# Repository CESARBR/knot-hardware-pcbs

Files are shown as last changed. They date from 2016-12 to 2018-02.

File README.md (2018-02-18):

# KNoT Hardware PCBs

Here you'll find all the design and outputs files of the hardware that supports KNoT platform application software. Since KNoT is an open-source project, the hardware development also follow the best practices suggested by the open source hardware association (OSHWA).

## Overview

KNoT project includes three board types:

1. Starter Boards
2. Development Boards
3. Reference Design Boards

### Starter Boards
This board offers support for the embedded software development and preliminary hardware evaluation. They're build by the integration of existing modules and are composed of microcontroller, radio and power supply circuit. This boards help popularization of the KNoT Platform because they are cheaper and easier to assembly and distribute to the community.

### Development Board
This PCB is self contained and has two goals: (i) to serve as a development platform with embedded firmware for prototypes that can be validated on field and (ii) to serve as baseline for specific hardware development for final products, as schematics and layouts can be rapidly customized to attend to specific demands.

### Reference Design
The Reference Design is composed of hardware, firmware and (eventually) desktop/mobile software. They are designed to demonstrate the KNoT platform used in real solutions. A Reference Design can be based on a Starter or Development Board tailored to be used in a specific solution.

## Available Boards

The KNoT Platform follows the hub-and-spoke architecture thus comprises of end-nodes, simply called Things, a Gateway to relay the Things messages and cloud applications. Therefore we have two kinds of boards, the Things which are based on [Arduino Pro Mini](https://www.arduino.cc/en/Guide/ArduinoProMini) and the Gateway which is based on a [Raspberry Pi 3](https://www.raspberrypi.org/products/raspberry-pi-3-model-b/).

### KNoT Gateway Starter Board

KNoT Gateway Starter Board consists of a shield board for Raspberry Pi 2 and 3. This shield disposes of:

- 2x8 female header for easily coupling a [nRF24L01+](https://www.nordicsemi.com/eng/Products/2.4GHz-RF/nRF24L01P) module for wireless communication with the KNoT Things
- 3.3V Low Dropout voltage regulator for more stable power feed
- 1x8 female header for coupling the Itead [PN532](https://www.itead.cc/wiki/ITEAD_PN532_NFC_MODULE) NFC card header
- 2x General purpose Push Buttons(with external pull-up resistor circuit and a capacitive high frequency filter)
- 3x General purpose red LEDs
- Prototyping area with 9x16 prototyping holes with 5V, 3V3 and GND connections.

All modules are mapped into the Raspberry Pi pins so no extra jumpers are required to use it, just need to connect the modules. (you can see pins connections in the gateway starter board schematic file).
The connection between the shield modules and the Raspberry Pi pins are made by a male/female 2x20 header thats fit in the Raspberry's GPIO header and ease the access to the Raspberry's GPIO.

### KNoT Gateway Mini Starter Board :new:

KNoT Gateway Mini Starter Board consists of a tiny shield board for Raspberry Pi and saves a lot of space and pins, since it only requires 16 pins from the Raspberry Pi 40-pin header. The board supports the nRF24L01+ radio module and also contains:
- 2x user buttons
  - Things Pairing: starts the pairing process to Things nearby
  - Reset: provides a way to reset the gateway firmware to default parameters
- 3x LEDs
  - Power
  - Connection Status
  - Activity

### KNoT Thing Starter Board

KNoT Thing Starter Board, currently on it third version (`Rev 01.02`) is a device board based on Arduino and nRF24L01+ radio. The board supports the composition of an [Arduino Pro Mini 5V 16MHz](https://www.arduino.cc/en/Main/arduinoBoardProMini), a nRF24L01+ 2.4GHz module and a [FTDI FL232 Module]().
The board also provides the KNoT Status LED and a Reset EEPROM button.

In addition, the board brings an user LED, connected to Arduinos PD5 pin. All the Arduino Pins are available on external headers where user can debug their applications or connect external devices, such as sensors or actuators.

All the board components are plated-through hole technology which makes it easy to manually assembly.

There is also a previous version of this board (`Rev 01.00`) available online on the Upverter E-CAD: [Thing Starter Board](https://upverter.com/CESARKNoT/ea9bba79e71df466/KNoT-nRF24L01/).

### KNoT Thing Development Board

KNoT Thing Development Board consists of an Arduino based PCB with the ATMega328 microcontroler, nRF24L01+ circuit, headers for SPI and I²C communication, push button and status led.

#### Characteristics

 - Supports KNoT version 01.00
 - Compatible with Arduino IDE
 - Supplied via Micro-USB connector
 - nRF24L01+ radio with external antenna
 - ATMega328-AU Micro-controller
 - Programmed through FTDI232RL USB-Serial converter

KNoT Thing DevBoard PCBs are compatible with the Arduino IDE and may be integrated with peripherals through expansion connectors.
Before using the PCB, it's important to burn the bootloader to the Atmega328 micro-controller. For this PCB, the Arduino Pro Mini 3.3V 8MHz bootloader is used ([ATmegaBOOT_168_atmega328_pro_8MHz.hex](https://github.com/arduino/Arduino/blob/master/hardware/arduino/avr/bootloaders/atmega/ATmegaBOOT_168_atmega328_pro_8MHz.hex)). The use of ICSP is recommended for burning the bootloader via the 3x2 header with SPI interface using an Atmel SPI Programmer and Atmel Studio. Besides burning the bootloader, the ATMega328 fuses also need to be programmed via ICSP with the values:
- Extended: 0xFD
- High: 0xDA
- Low: 0xFF

## Development tools

The ECAD tool used is Altium Designer versions 14.2.3 and 14.2.4.

## PCB Files

Each PCB project includes the design files:
 - Components Library
 - Schematics
 - Board Layout

The generated output files are:
 - Bill Of Materials (BOM)
 - Gerber
 - NC Drill
 - PCAD Netlist
 - Assembly Drawing
 - Composite Drawing
 - Pick and Place
 - Schematics (PDF)

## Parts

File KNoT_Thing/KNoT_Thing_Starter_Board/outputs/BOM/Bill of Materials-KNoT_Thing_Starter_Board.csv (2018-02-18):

Comment | Designator | LibRef | Quantity | Supplier 1 | Supplier Part Number 1
CAPC_RADIAL_100 | C1 | CAPC1608L_1 | 1 | Digi-Key | P1175-ND
STATUS | D1 | LED | 1 | Digi-Key | 160-1853-ND
USER | D2 | LED | 1 | Digi-Key | 160-1852-ND
Header 2H | J1, J2, J4, JP1 | Header 2H | 4
Header 6 | J3, J5, J6 | Header 6 | 3
Header 4 | J7 | Header 4 | 1
Arduino Pro Mini 5V 16MHz | MD1 | Arduino Pro Mini 5V 16MHz | 1
nRF24L01+ | MD2 | nRF24L01+ Module | 1
Female header for FTDI module | MD3 | Module_FTDI | 1
Res1 | R1 | Res1 | 1 | Digi-Key | CF18JT10K0CT-ND
Res1 | R2, R3 | Res1 | 2 | Digi-Key | CF18JT150RCT-ND
CLR_EEPROM | S1 | SW-PB | 1 | Digi-Key | 450-1804-ND

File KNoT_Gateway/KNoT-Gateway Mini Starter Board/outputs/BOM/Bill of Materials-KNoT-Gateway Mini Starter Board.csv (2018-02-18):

Comment | Designator | LibRef | Quantity | Supplier 1 | Supplier Part Number 1
Cap 0805 0.1uF | C1 | Cap_0805_0.1uF | 1 | Digi-Key | 445-8883-1-ND
Cap 0805 10uF | C2 | Cap_0805_10uF | 1 | Digi-Key | 709-1229-1-ND
Female 2x8 header | J1 | 2x8 RPi Header | 1 | Digi-Key | S7076-ND
2x4 Female Header | J2 | nRF24L01+ | 1 | Digi-Key | S7107-ND
LED RADIAL 5MM RED | LED1 | LED RADIAL 5MM RED | 1 | Digi-Key | 160-1853-ND
LED RADIAL 5MM GREEN | LED2, LED3 | LED RADIAL 5MM GREEN | 2 | Digi-Key | 160-1852-ND
RES_0805 | R1, R2, R3 | RES_0805 | 3 | Digi-Key | 311-100ARCT-ND
RES_0805 | R4, R5 | RES_0805 | 2 | Digi-Key | 311-4.7KARCT-ND
Push Button - Long | S1 | Push Button L | 1 | Digi-Key | P10880S-ND
Push Button - Short | S2 | Push Button S | 1 | Digi-Key | P10883S-ND

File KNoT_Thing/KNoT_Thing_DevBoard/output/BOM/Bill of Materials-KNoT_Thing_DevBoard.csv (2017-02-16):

Comment | Description | Designator | Footprint | LibRef | Quantity | Supplier 1 | Supplier Part Number 1
Header 7 | Header, 7-Pin | ANALOG IN, DIGITAL | HDR1X7 | Header 7 | 2
Cap_0402 | Chip Capacitor 0402 (1005 metric) | C1, C2, C5, C17, C19 | CAPC1005L | Capacitor_0402 | 5 | Digi-Key | 311-1731-1-ND
Cap_0402 | Chip Capacitor 0402 (1005 metric) | C3, C4 | CAPC1005L | Capacitor_0402 | 2 | Digi-Key | 311-1415-1-ND
Cap_0402 | Chip Capacitor 0402 (1005 metric) | C6, C16 | CAPC1005L | Capacitor_0402 | 2 | Digi-Key | 311-1703-1-ND
Cap_0402 | Chip Capacitor 0402 (1005 metric) | C7 | CAPC1005L | Capacitor_0402 | 1 | Digi-Key | 311-1352-1-ND
Cap_0402 | Chip Capacitor 0402 (1005 metric) | C8 | CAPC1005L | Capacitor_0402 | 1 | Digi-Key | 311-1003-1-ND
Cap_0402 | Chip Capacitor 0402 (1005 metric) | C9, C12 | CAPC1005L | Capacitor_0402 | 2 | Digi-Key | 311-1018-1-ND
Cap_0402 | Chip Capacitor 0402 (1005 metric) | C10 | CAPC1005L | Capacitor_0402 | 1 | Digi-Key | 311-2076-1-ND
Cap_0402 | Chip Capacitor 0402 (1005 metric) | C11 | CAPC1005L | Capacitor_0402 | 1 | Digi-Key | 311-1704-1-ND
Cap_0402 | Chip Capacitor 0402 (1005 metric) | C13 | CAPC1005L | Capacitor_0402 | 1 | Digi-Key | 311-1367-1-ND
Cap_0402 | Chip Capacitor 0402 (1005 metric) | C14 | CAPC1005L | Capacitor_0402 | 1 | Digi-Key | 311-1707-1-ND
Cap0603 | 4.7µF 10V Ceramic Capacitor X5R 0603 | C18, C20 | CAPC1608L | Cap0603 | 2 | Digi-Key | 311-1453-1-ND
0402L050SLKR | PTC Resettable Fuse 6V 500mA Ih Surface Mount 0402 (1005 Metric), Concave | F1 | 0805L | Fuse 2 | 1 | Digi-Key | F2772CT-ND
Header 6 | Header, 6-Pin | I2C | HDR1X6 | Header 6 | 1
32K249-400L5 | SMA Right Angle Jack, Up to 18 GHz, -65 to 165 degC | J2 | ROS-32K249-400L5_V | 32K249-400L5 | 1 | Digi-Key | ARFX1232-ND
Header 3X2 | Header, 3-Pin, Dual row | J5 | HDR2X3 | Header 3X2 | 1
Inductor0402 | Inductor 27nH | L1 | CAPC1005L | Inductor0402 | 1 | Digi-Key | A103711CT-ND
Inductor0402 | Inductor 27nH | L2 | CAPC1005L | Inductor0402 | 1 | Digi-Key | A102559CT-ND
Inductor0402 | Inductor 27nH | L3 | CAPC1005L | Inductor0402 | 1 | Digi-Key | A103706CT-ND
Ferrite | BLM18AG121SN1 FERRITE 120 OHM 500MA 0603 | L4 | 0603-cap | Ferrite | 1 | Digi-Key | 445-2166-1-ND
LED 0603 | LED SMD 0603 | LED1 | 0603_LED | LED 0603 | 1 | Digi-Key | 754-1790-1-ND
LED 0603 | LED SMD 0603 | LED2 | 0603_LED | LED 0603 | 1 | Digi-Key | 754-1789-1-ND
Header 2H | Header, 2-Pin, Right Angle | POWER | HDR1X2 | Header 2H | 1
RES_0402 | Precision Thick Film Chip Resistor, 10 Ohm to 1M Ohm Range, 1% and 0.5% Tolerance, 0805 Size, 1/8 W | R1, R7 | CAPC1005L | RES_0402 | 2 | Digi-Key | 311-2131-1-ND
RES_0402 | Precision Thick Film Chip Resistor, 10 Ohm to 1M Ohm Range, 1% and 0.5% Tolerance, 0805 Size, 1/8 W | R2 | CAPC1005L | RES_0402 | 1 | Digi-Key | 311-22KJRCT-ND
RES_0402 | Precision Thick Film Chip Resistor, 10 Ohm to 1M Ohm Range, 1% and 0.5% Tolerance, 0805 Size, 1/8 W | R3 | CAPC1005L | RES_0402 | 1 | Digi-Key | 311-1.0MJRCT-ND
RES_0402 | Precision Thick Film Chip Resistor, 10 Ohm to 1M Ohm Range, 1% and 0.5% Tolerance, 0805 Size, 1/8 W | R4, R5 | CAPC1005L | RES_0402 | 2 | Digi-Key | 311-330JRCT-ND
RES_0402 | Precision Thick Film Chip Resistor, 10 Ohm to 1M Ohm Range, 1% and 0.5% Tolerance, 0805 Size, 1/8 W | R6 | CAPC1005L | RES_0402 | 1 | Digi-Key | 311-0.0JRTR-ND
SW-SPST | Single-Pole, Single-Throw Switch | S1, S2 | SWITCH TS-1181 | SW-SPST | 2 | Digi-Key | CKN10384CT-ND
ATmega328-AU | 8-bit AVR Microcontroller, 32KB Flash, 1KB EEPROM, 2KB SRAM, 32-pin TQFP, Industrial Grade (-40°C to 85°C) | U1 | 32A_L | ATmega328-AU | 1 | Digi-Key | ATMEGA328-AU-ND
nRF24L01+ QFN20 | IC RF TxRx Only General ISM > 1GHZ 2.4GHz | U2 | QFN20 | nRF24L01+ | 1 | Digi-Key | 1490-1019-ND
FT232RL-Reel | USB UART Asynchronous Serial Data Transfer Chip, 28-pin SSOP, Tape and Reel | U3 | SSOP-28_N | FT232RL-Reel | 1 | Digi-Key | 768-1007-6-ND
MIC5205-3.3YM5 | Voltage Regulator | U4 | SOT23-5 | MIC5205-3.3YM5 | 1 | Digi-Key | 576-1259-1-ND
ZX62-B-5PA-33 | USB Connector | USB | Micro USB b | ZX62-B-5PA-33 | 1 | Digi-Key | H125270CT-ND
8 MHz | Crystal FOXSLF/080-20 | Y1 | CX5032GB | XTAL | 1 | Digi-Key | 1253-1373-1-ND
16 MHz | Crystal FOXSLF/080-20 | Y2 | SPK-16M-5032 | XTAL_SMD | 1 | Digi-Key | 887-1708-1-ND

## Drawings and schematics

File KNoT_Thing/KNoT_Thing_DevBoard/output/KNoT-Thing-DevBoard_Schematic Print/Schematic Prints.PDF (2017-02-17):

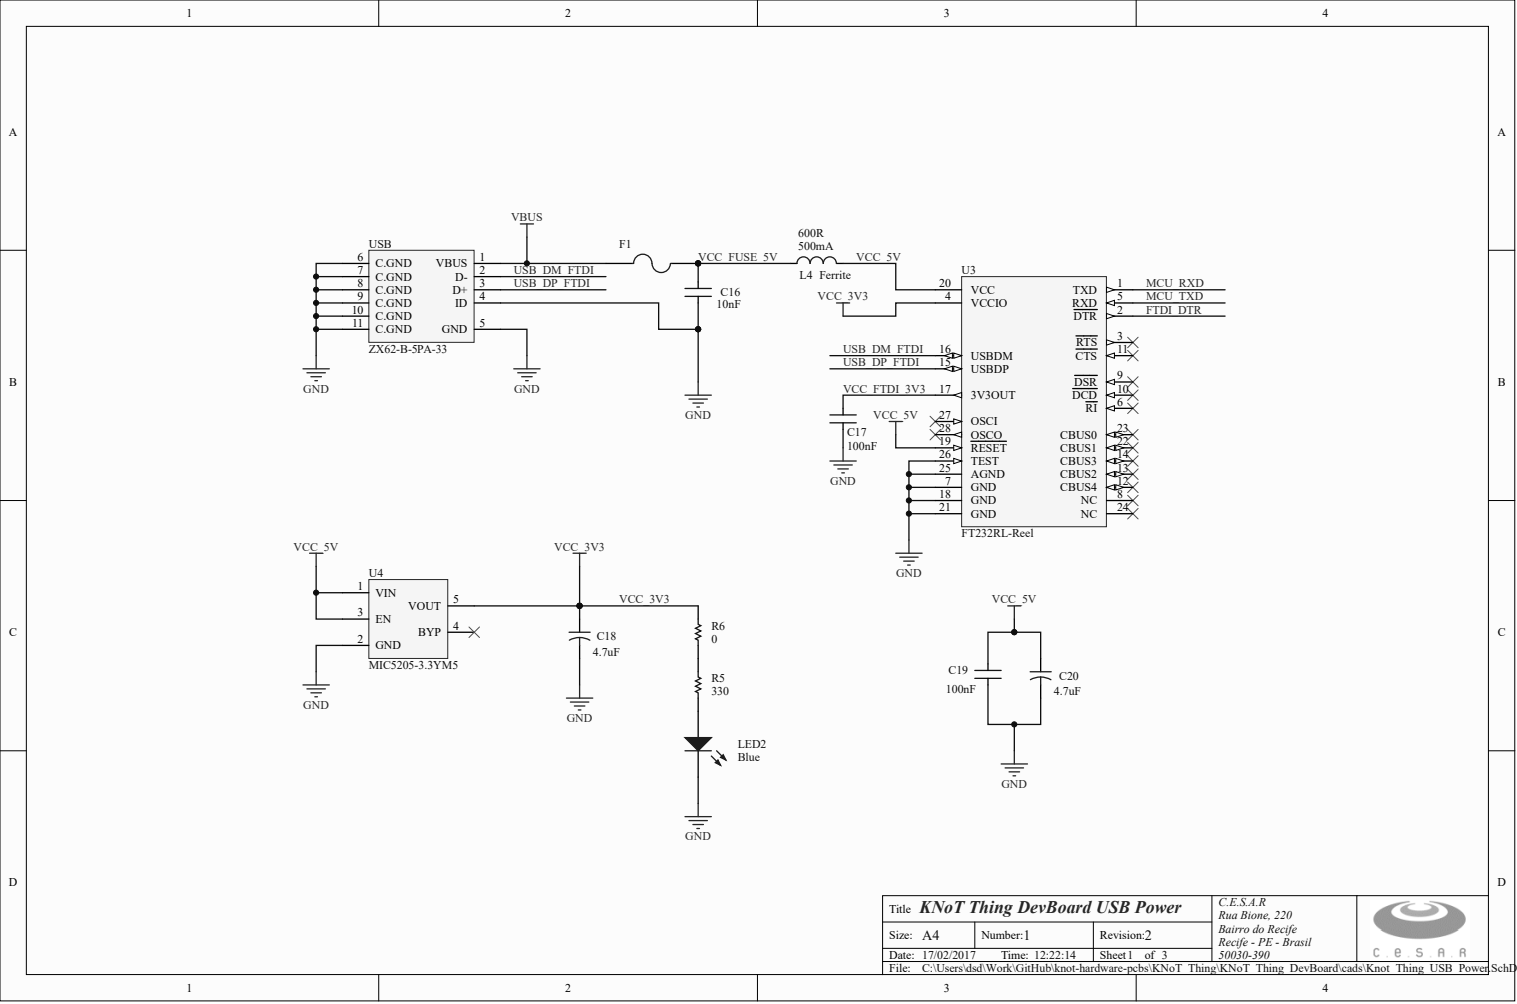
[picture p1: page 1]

AGND 25 TEST 26

GND 7

GND 21

KNoT Thing DevBoard USB Power Title | C.E.S.A.R Rua Bione, 220 Bairro do Recife Recife - PE - Brasil 50030-390

Size: A4 | Number: 1 | Revision: 2
Date: 17/02/2017 Time: 12:22:14 | | Sheet of 3

C:\Users\dsd\Work\GitHub\knot-hardware-pcbs\KNoT_Thing\KNoT_Thing_DevBoard\cads\Knot_Thing_USB_Power.SchDoc

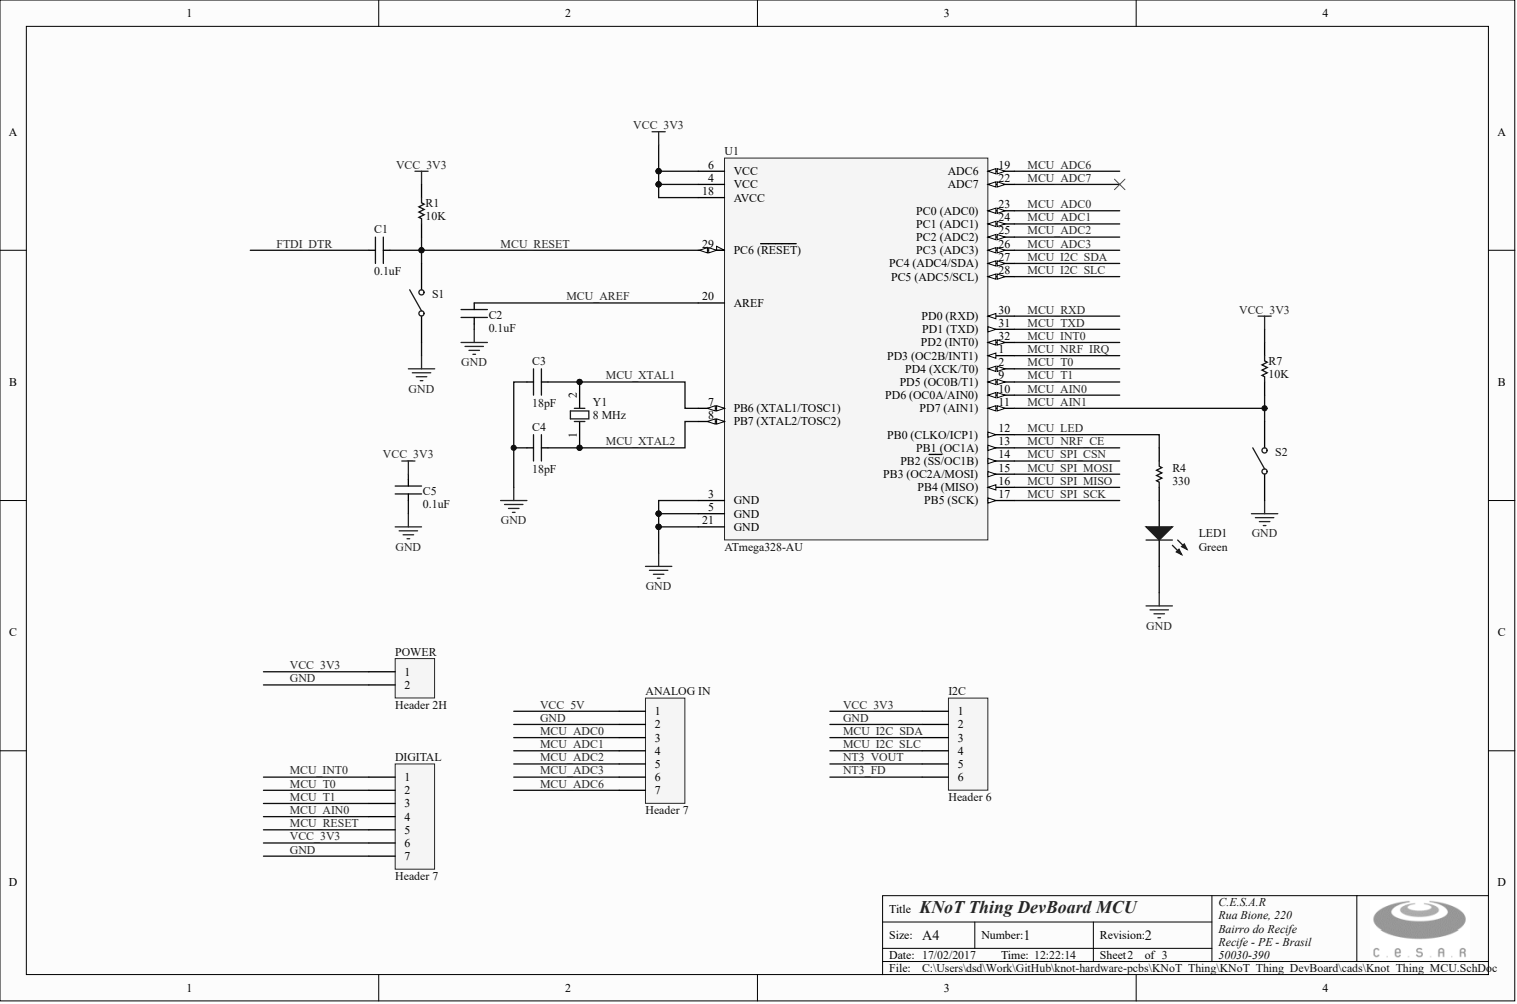
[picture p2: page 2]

AREF 20

Y1
8 MHz 8 | | MCU_LED

MCU_XTAL 2 | 3

MCU_NRF_CE

KNoT Thing DevBoard MCU 1
Title

C:\Users\dsd\Work\GitHub\knot-hardware-pcbs\KNoT_Thing\KNoT_Thing_DevBoard\cads\Knot_Thing_MCU.SchDoc

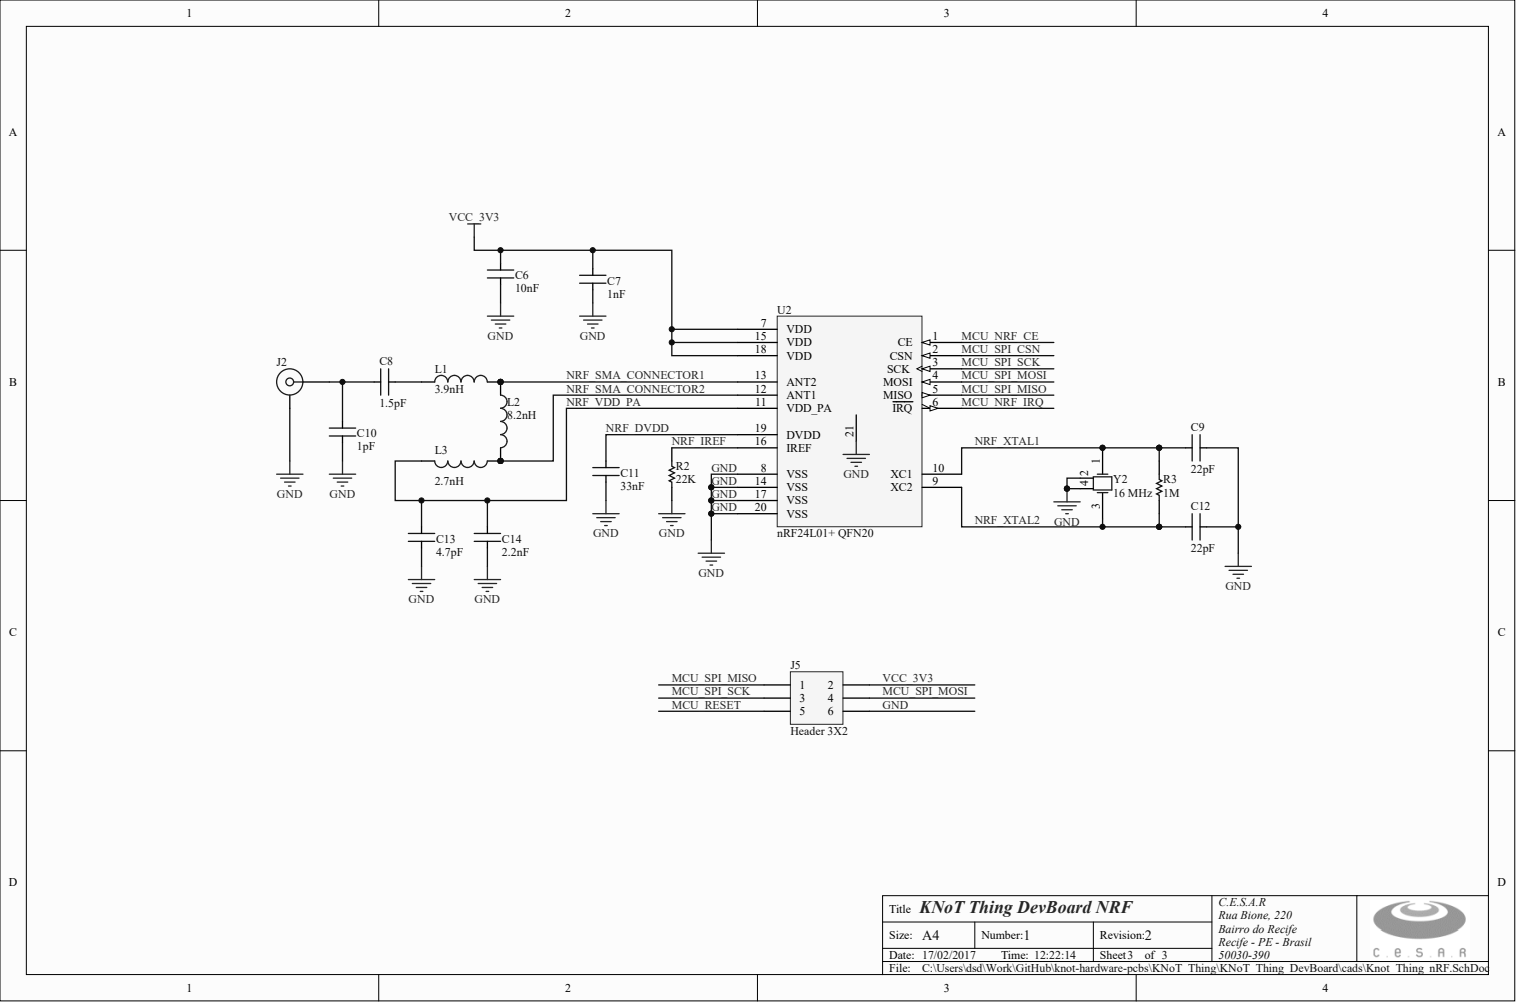
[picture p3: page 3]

L2 NRF_VDD_PA

NRF_DVDD | DVDD 19

IREF 16

GND | VSS 14 | | Y2
GND | VSS 17
GND | VSS 20

KNoT Thing DevBoard NRF Title | C.E.S.A.R Rua Bione, 220

C:\Users\dsd\Work\GitHub\knot-hardware-pcbs\KNoT_Thing\KNoT_Thing_DevBoard\cads\Knot_Thing_nRF.SchDoc

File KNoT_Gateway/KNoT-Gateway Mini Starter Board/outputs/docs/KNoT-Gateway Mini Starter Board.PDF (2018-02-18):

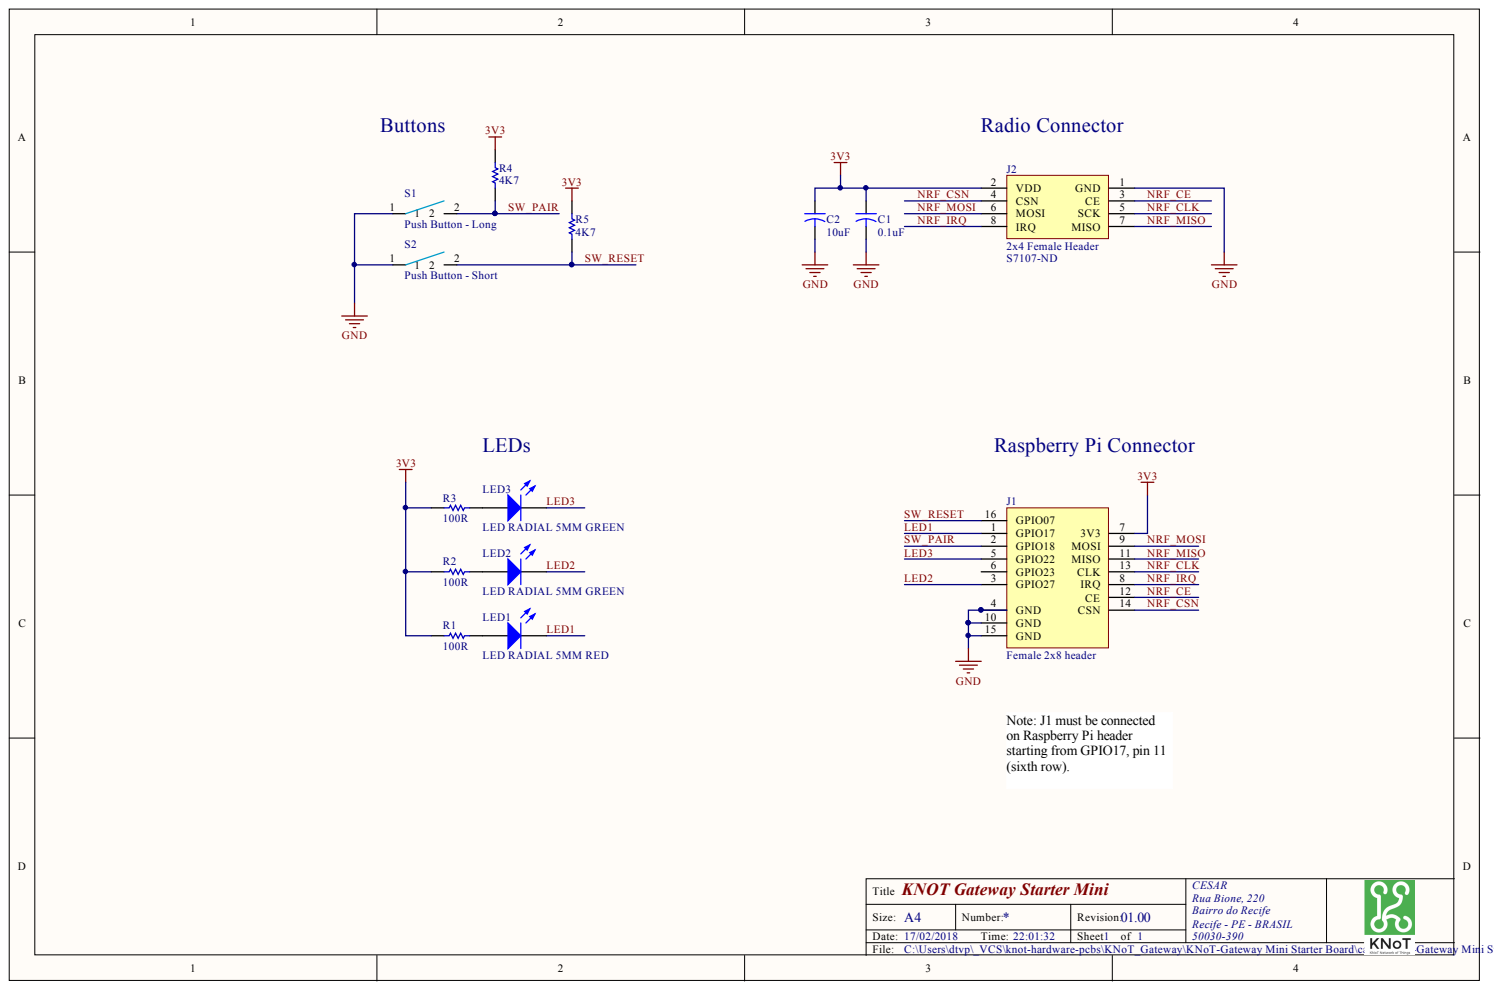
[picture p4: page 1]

VDD 2 CSN 4 CE MOSI 6 IRQ 8 SCK | 3 5 | NRF_CE NRF_CLK

NRF_MISO

Note: J1 must be connected
on Raspberry Pi header
starting from GPIO17, pin 11
(sixth row).

Title KNOT Gateway Starter Mini | Rua Bione, 220 CESAR Bairro do Recife Recife - PE - BRASIL 50030-390

Size: A4 | Number: * | Revision: 01.00

1 2 | Date: 17/02/2018 Time: 22:01:32 Sheet 1 of 1 File: 3 4

C:\Users\dtvp\_VCS\knot-hardware-pcbs\KNoT_Gateway\KNoT-Gateway Mini Starter Board\cads\KNoT-Gateway Mini Starter Board.SchDoc

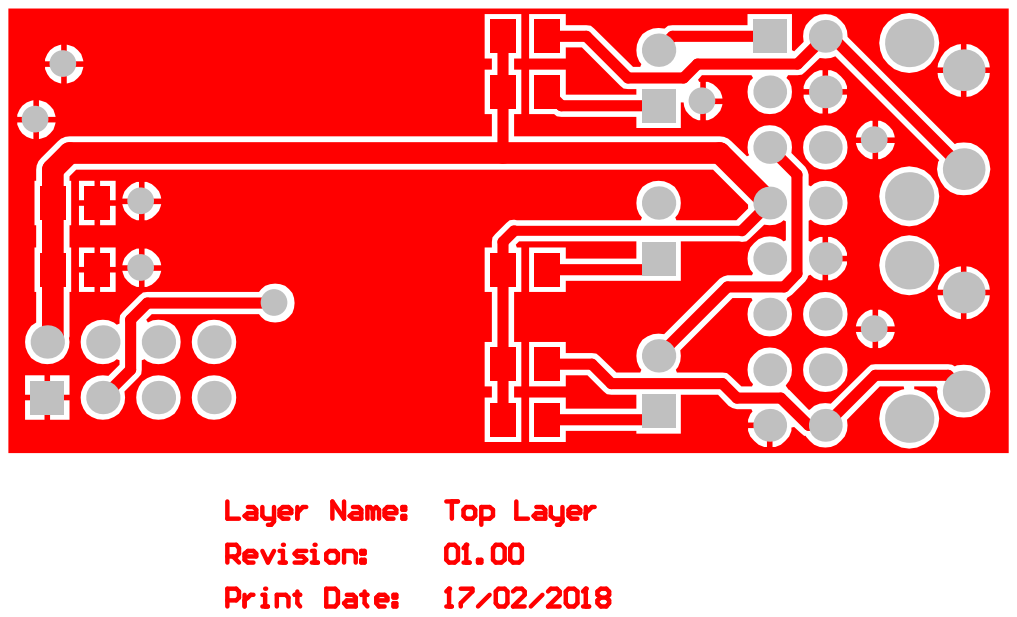
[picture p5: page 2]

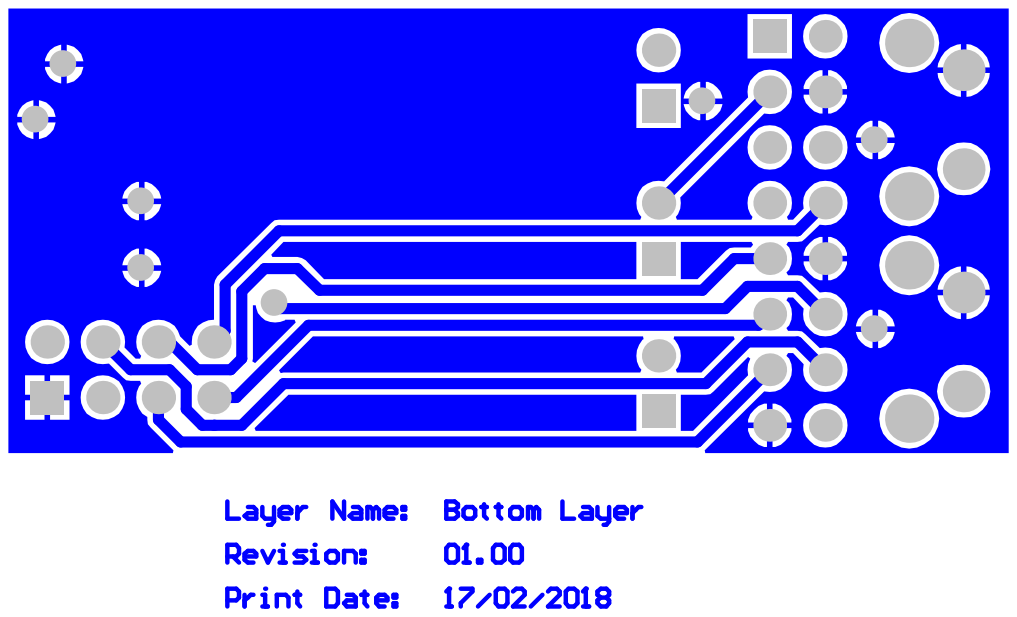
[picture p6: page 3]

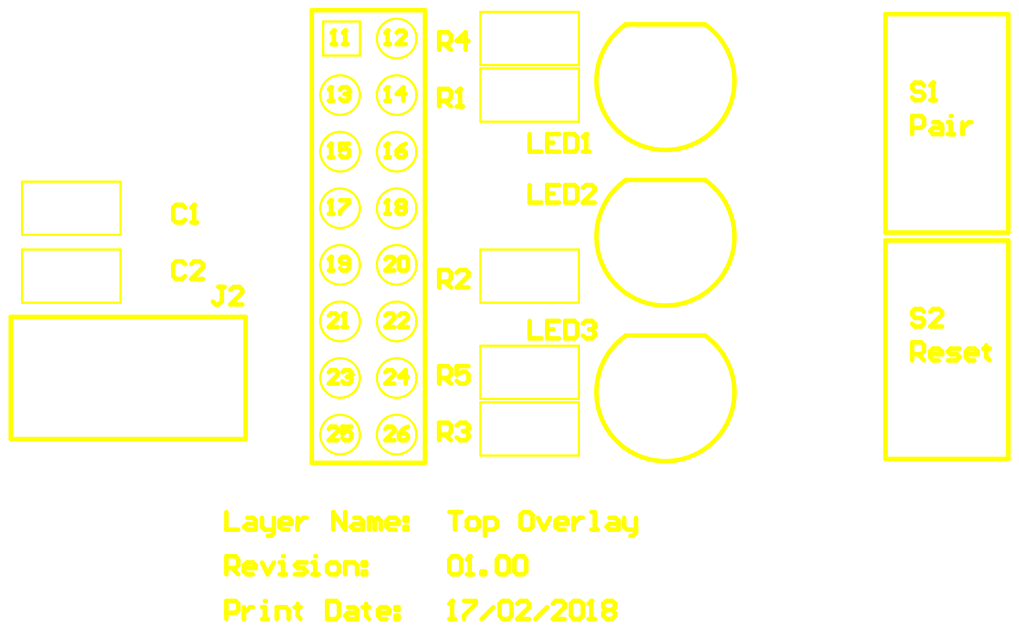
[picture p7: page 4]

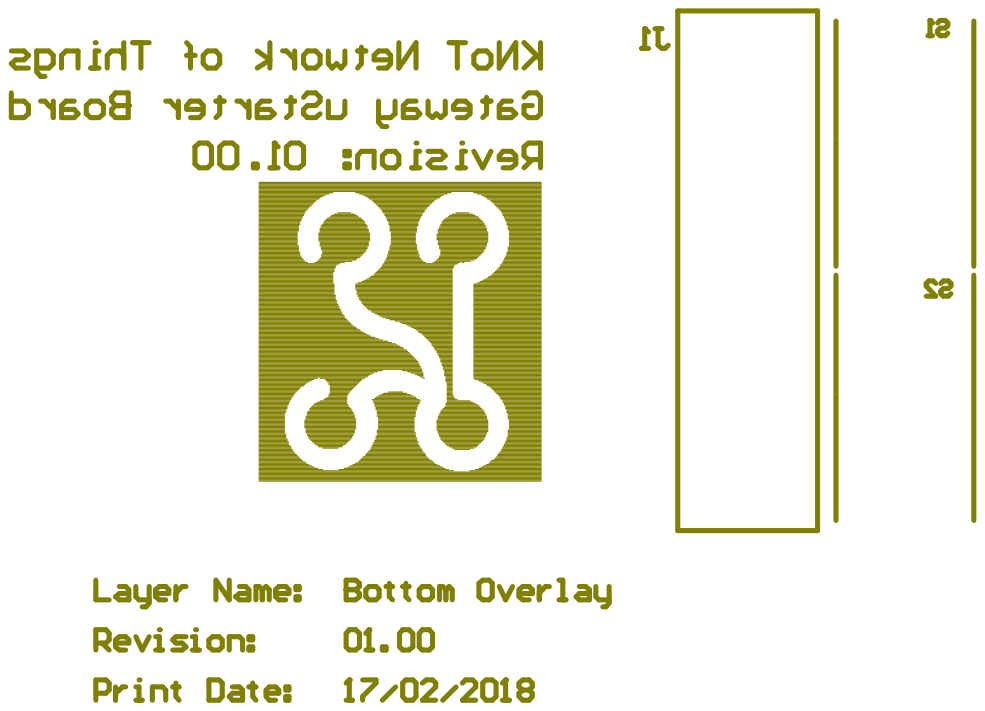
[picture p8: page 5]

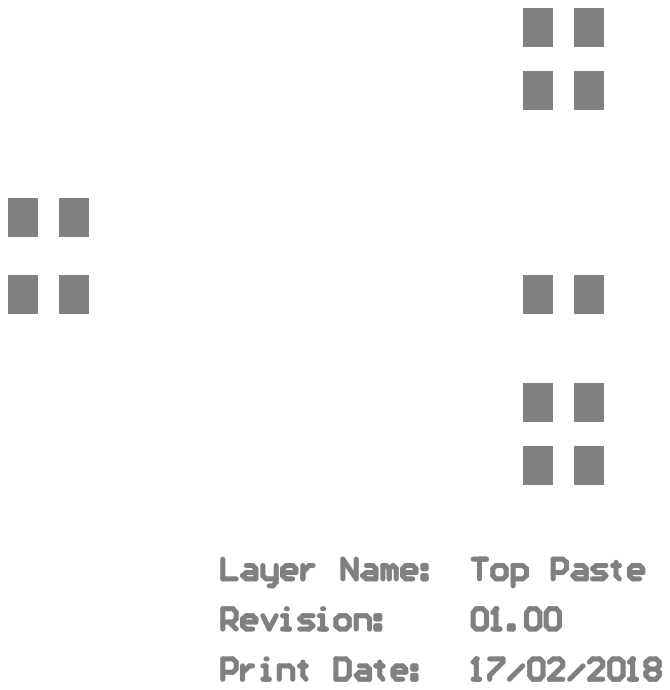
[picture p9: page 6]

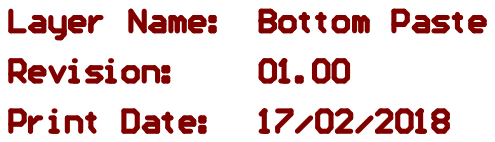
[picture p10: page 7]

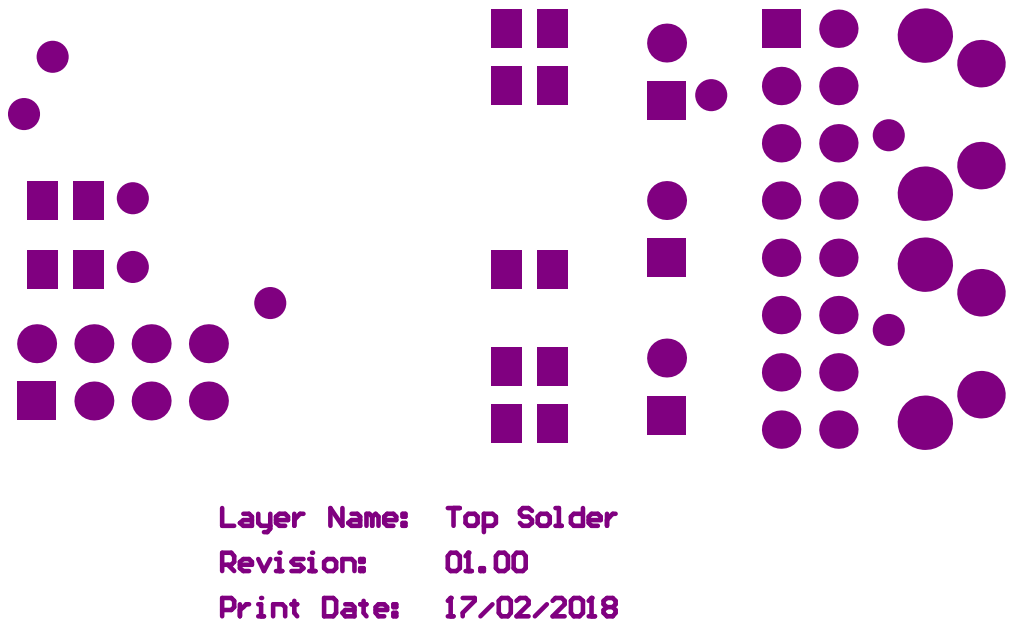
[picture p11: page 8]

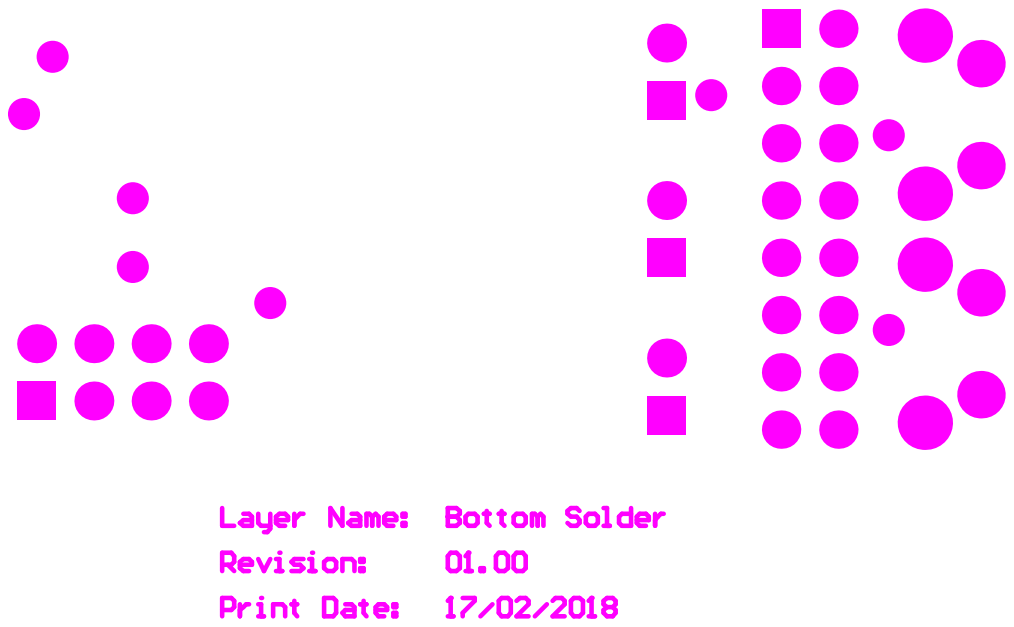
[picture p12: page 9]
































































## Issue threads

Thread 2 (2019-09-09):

Run full test KNoT Mesh

jcorde, 2019-09-09:
Execute tests to verify if KNoT Mesh is able to run a sample app.

In case of failure, test using the Raytec board.

Closed 2019-09-20.

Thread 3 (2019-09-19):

Turn LEDs on at high for KNoT Mesh

jcorde, 2019-09-19:
The version 1.0 of KNoT mesh will turn its LEDs on if the pins connected to it are High.
This not a recommended behavior as there will be extra current going out of the microcontroller.

Fix it by setting the LEDs to turn on at Low.

CC: @gabriellaalencar and @gsipkoi.

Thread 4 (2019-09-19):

Fix analog channels routes for KNoT Mesh

jcorde, 2019-09-19:
The analog pins for KNoT Mesh are labeled to the wrong pinout.

A good example is pin 0.31, which should be tagged as channel 7, but is tagged as channel 3.

Actual layout:
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

Reference pinout:
https://infocenter.nordicsemi.com/topic/ps_nrf52840/pin.html?cp=3_0_0_6_0_0#aqfn73

CC: @gabriellaalencar and @gsipkoi.

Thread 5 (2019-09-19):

Give access to more peripherals for KNoT Mesh

jcorde, 2019-09-19:
KNoT Mesh has no access to various peripherals, such as PWM, I2C_1, I2C_2, SPI_0,1,2,3, UART_1...

Make these pins available and sign them at the silk layer.

CC: @gabriellaalencar and @gsipkoi.

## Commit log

2016-12-21 Add first revision of KNoT Gateway Starter board and KNoT Thing Development Board. PCB projects were designed on Altium Designer.
    [Bill of Materials-KNoT_Thing_DevBoard.csv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]
2016-12-27 Sync of schematic and pcb.
    - Fix warnings (pcb and library)
    - Added layer labels
    - CESAR KNoT Thing
    DevBoard on top silkscreen
    [Bill of Materials-KNoT_Thing_DevBoard.csv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]
2016-12-28 Removing preview, history and desktop.ini
    Removing unecessary files
    [KNoT_Thing_DevBoard.PcbDoc, KNoT_Thing_DevBoard.PrjPCB]
2017-01-24 Hardware project desctiption
    Description of the knot pcbs project: tools and files.
2017-02-03 Boards description
    Briefly describing the boards: knot gateway starter board and knot thing
    development board
2017-02-10 Creating DTR connection. Removing diff pair capacitors.
    Creating DTR connection and correcting the capacitor.
    Removing diff pair capacitors that were not necessary.
    [KNoT_Thing_DevBoard.PcbDoc, KNoT_Thing_DevBoard.PrjPCB, Knot_Thing_MCU.SchDoc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]
2017-02-10 New version of USB connector
    Correcting the usb connector to non inverted version.
    [KNoT_Thing_DevBoard.PcbDoc, Knot_Thing_USB_Power.SchDoc]
2017-02-13 Fixing headers, crystal and including led.
    Fixing headers pins order and labels.
    Including a blue led and resistors for power indication.
    Fixing crystal Y2 partnumber.
    [Bill of Materials-KNoT_Thing_DevBoard.csv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]
2017-02-13 Removing old schematic pdf generated
2017-02-13 Removing old pcb print pdf files
2017-02-14 Including clear eeprom button, removing byp capacitor...
    Including clear eeprom push button active low.
    Removing bypass capacitor from LDO.
    Repositioning components.
    Correcting headers.
    A7 free for random generation.
    [KNoT_Thing_DevBoard.PcbDoc, Knot_Thing_MCU.SchDoc, Knot_Thing_USB_Power.SchDoc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]
2017-02-15 Changing fuse footprint to 0805
    Changing fuse footprint to 0805.
    Generating outputs.
    [Bill of Materials-KNoT_Thing_DevBoard.csv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]
2017-02-16 Including KNoT logo, fixing usb 3d mec layer,
    Including knot logo, board label and revision on bottom overlay.
    Fixing usb mechanical layer.
    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
    [Bill of Materials-KNoT_Thing_DevBoard.csv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]
2017-02-17 Fixing bottom gnd plane to avoid island
    Removing island from bottom ground plane.
    Generating outputs for revision 2.
    [KNoT_Thing_DevBoard.GBL, KNoT_Thing_DevBoard.GBO, KNoT_Thing_DevBoard.GBP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]
2017-02-20 Update Readme with boards and bootloader details
2017-02-23 Update Readme: describing pcb types
2017-03-03 Add KNoT gateway starter board info
2017-03-07 Including antenna 3D body
    Including antenna 3D body to sma connector
    [KNoT_Thing_DevBoard.PcbDoc]
2017-03-07 Revert "Including antenna 3D body"
    This reverts commit a0d7c5da580d963a160336d4c16d8706262469e0.
    [KNoT_Thing_DevBoard.PcbDoc]
2017-03-07 Correcting antenna 3D body
    Correcting antenna 3D body mechanical layer
    [KNoT_Thing_DevBoard.PcbDoc]
2017-03-14 Replacing fixation vias with pads
    Replacing fixation vias with pads for correcting generating the 3D step
    of the PCB
    [KNoT_Thing_DevBoard.PcbDoc]
2017-03-20 Creating Knot thing starter board in altium designer
    [KNoT_Thing_Starter_Board.PcbDoc, KNoT_Thing_Starter_Board.PrjPCB, Power_USB.SchDoc]
2017-03-21 Finishing the starter PCB routing and GND planes
    Finishing the starter PCB routing and GND planes
    Needs revision
    [KNoT_Thing_Starter_Board.PcbDoc]
2017-03-21 Re-routing PCB traces
    Re-router to get shortter traces
    [KNoT_Thing_Starter_Board.PcbDoc, KNoT_Thing_Starter_Board.PrjPCB, Power_USB.SchDoc]
2017-03-22 Including top overlay, fixing holes, fixing tracks
    KNoT Thing Starter Kit Rev 01.01
    [KNoT_Thing_DevBoard.PcbDoc, KNoT_Thing_Starter_Board.PcbDoc, KNoT_Thing_Starter_Board.PrjPCB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]
2017-03-22 Minor changes on schematic and fix some DRC on PCB.
    [KNoT_Thing_Starter_Board.PcbDoc, KNoT_Thing_Starter_Board.PrjPCB, KNoT_Thing_Starter_Board.SchDoc]
2017-03-22 Including KNoT Logo and fixing design violations
    [KNoT_Thing_Starter_Board.PcbDoc, KNoT_Thing_Starter_Board.PrjPCB]
2017-03-22 Added a wire jumper so user can decide to use external 3.3V instead of FTDI's.
    [KNoT_Thing_Starter_Board.PcbDoc, KNoT_Thing_Starter_Board.PrjPCB, KNoT_Thing_Starter_Board.SchDoc]
2017-03-23 Including supplier partnumbers and generating BOM
    [Bill of Materials-KNoT_Thing_Starter_Board.csv, KNoT_Thing_Starter_Board.PcbDoc, KNoT_Thing_Starter_Board.PrjPCB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]
2017-03-23 Correcting 3V3 - C1 connection and BOM
    [Bill of Materials-KNoT_Thing_Starter_Board.csv, KNoT_Thing_Starter_Board.PcbDoc, KNoT_Thing_Starter_Board.SchDoc]
2017-03-23 Fix the output job file to generate manufacture and assembly files.
    [Bill of Materials-KNoT_Thing_Starter_Board.csv, KNoT_Thing_Starter_Board.PcbDoc]
2018-02-18 Adding a new PCB project for the gateway: Knot Gateway Starter Mini. Some library upgrade was also needed.
    [KNoT-Gateway Mini Starter Board.PcbDoc, KNoT-Gateway Mini Starter Board.PrjPCB, KNoT-Gateway Mini Starter Board.SchDoc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]
2018-02-18 Adding documentation and manufacturing output files for Gateway Mini Starter Board.
    [Bill of Materials-KNoT-Gateway Mini Starter Board.csv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]
2018-02-18 Adding new components on Thing component library to support a new version of Thing Starter Board.
2018-02-18 Add a new revision for Knot Thing Starter Board. Rev 01.02. All components now are PTH and FTDI in included in its module version. PCB now has a clear eeprom button and two LEDs: a Status LED to indi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
    [KNoT_Thing_Starter_Board.PrjPCB, KNoT_Thing_Starter_Board.SchDoc]
2018-02-18 Add SCH, PCB documentation, BOM and manufacturer files (Gerber and NC Drill) for Thing Starter Board revision 01.02.
    [Bill of Materials-KNoT_Thing_Starter_Board.csv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]
2018-02-18 Update the README.md to support the newest board: Gateway Mini and Thing Starter Rev. 01.02.
